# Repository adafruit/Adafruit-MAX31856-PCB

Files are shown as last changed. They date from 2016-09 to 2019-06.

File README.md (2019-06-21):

## Adafruit MAX31856 PCB

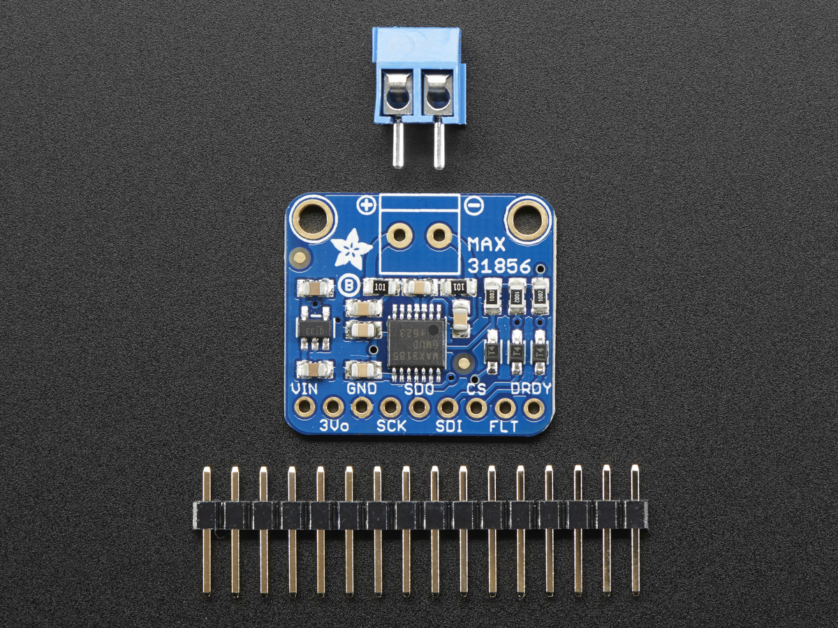
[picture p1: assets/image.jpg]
<a href="http://www.adafruit.com/products/3263"><br/>
Click here to purchase one from the Adafruit shop</a>

PCB files for the Adafruit MAX31856 Thermocouple Amplifier Breakout. Format is EagleCAD schematic and board layout
* https://www.adafruit.com/product/3263

### Description

Thermocouples are very sensitive, requiring a good amplifier with a cold-compensation reference, as well as calculations to handle any non-linearities. For a long time we've suggested our MAX31855K breakout, which works great but is only for K-type thermocouples. Now we're happy to offer a great new thermocouple amplifier/converter that can handle just about any type of thermocouple, and even has the ability to give you notification when the temperature goes out of range, or a fault occurs. Very fancy!

This converter communicates over 4-wire SPI and can interface with any K, J, N, R, S, T, E, or B type thermocouple.

This breakout does everything for you, and can be easily interfaced with any microcontroller, even one without an analog input. This breakout board has the chip itself, a 3.3V regulator and level shifting circuitry, all assembled and tested. Comes with a 2 pin terminal block (for connecting to the thermocouple) and pin header (to plug into any breadboard or perfboard). We even added inline resistors and a filter capacitor on-board for better stability, as recommended by Maxim. Goes great with our 1m K-type thermocouple or any other thermocouple, really!

### License

Adafruit invests time and resources providing this open source design, please support Adafruit and open-source hardware by purchasing products from [Adafruit](https://www.adafruit.com)!

Designed by Limor Fried/Ladyada for Adafruit Industries.

Creative Commons Attribution/Share-Alike, all text above must be included in any redistribution. See license.txt for additional details.

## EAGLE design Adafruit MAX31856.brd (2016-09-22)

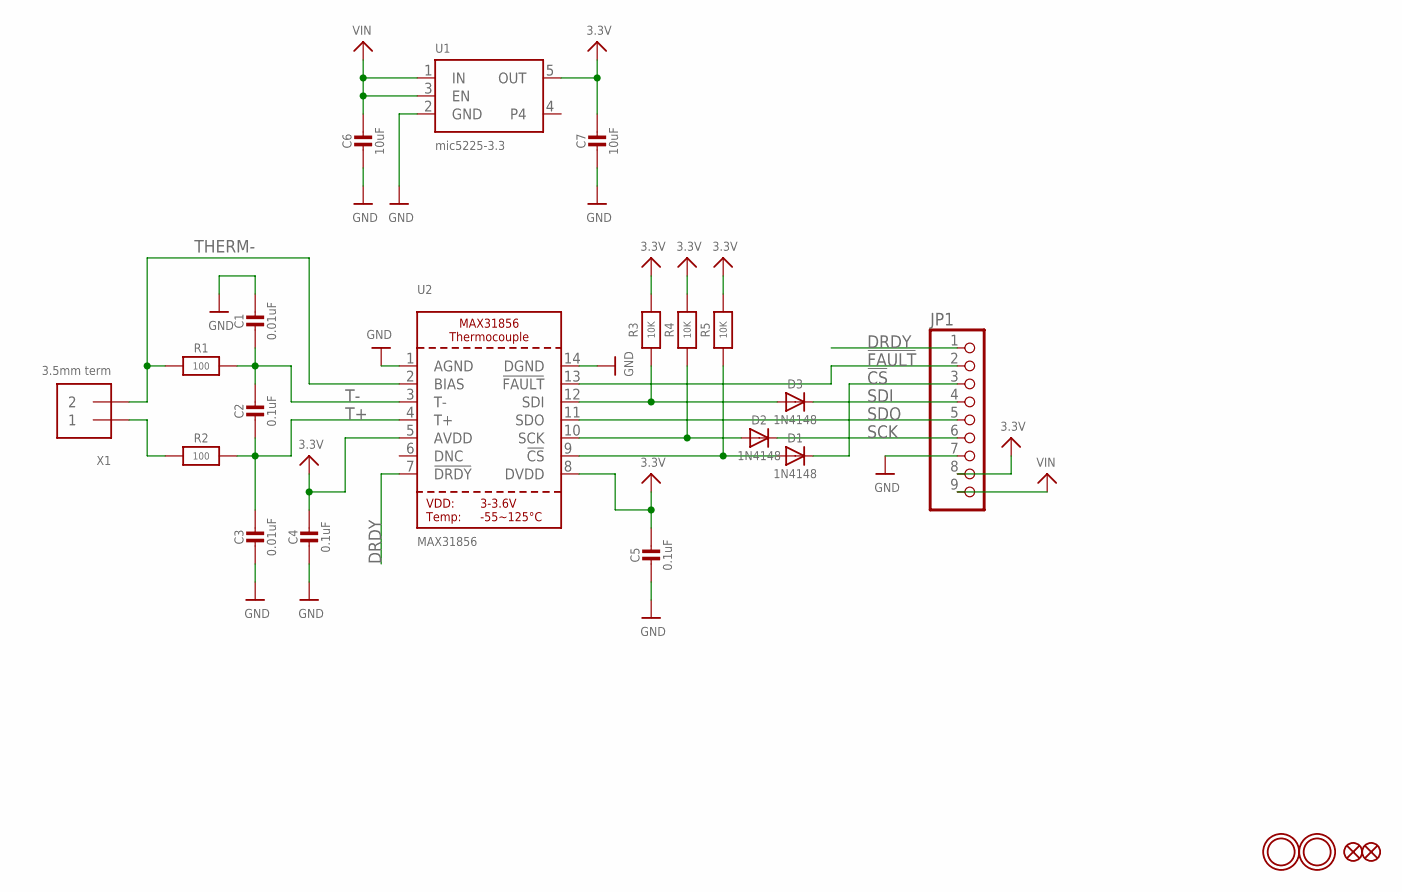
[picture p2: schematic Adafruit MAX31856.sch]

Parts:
C1: 0.01uF; 0805_10MGAP
C2, C4, C5: 0.1uF; 0805-NO
C3: 0.01uF; 0805-NO
C6, C7: 10uF; 0805-NO
D1, D2, D3: 1N4148; SOD-323
FID1, FID2: FIDUCIAL""; FIDUCIAL_1MM
JP1: HEADER-1X970MIL; 1X09_ROUND_70
R1, R2: 100; 0805-NO
R3, R4, R5: 10K; 0805-NO
U1: mic5225-3.3; SOT23-5
U2: MAX31856; TSSOP14
U$13, U$14: MOUNTINGHOLE2.5; MOUNTINGHOLE_2.5_PLATED
X1: 3.5mm term; TERMBLOCK_1X2-3.5MM

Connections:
3.3V: C4.1, C5.1, C7.1, JP1.8, R3.2, R4.2, R5.2, U1.5 (OUT), U2.5 (AVDD), U2.8 (DVDD)
!CS: D1.C, JP1.3
!CS_3V: D1.A, R5.1, U2.9 (!CS)
!FAULT: JP1.2, U2.13 (!FAULT)
DRDY: JP1.1, U2.7 (!DRDY)
GND: C1.1, C3.2, C4.2, C5.2, C6.2, C7.2, JP1.7, U1.2 (GND), U2.1 (AGND), U2.14 (DGND)
SCK: D2.C, JP1.6
SCK_3V: D2.A, R4.1, U2.10 (SCK)
SDI: D3.C, JP1.4
SDO: JP1.5, U2.11 (SDO)
SDO_3V: D3.A, R3.1, U2.12 (SDI)
T+: C2.2, C3.1, R2.2, U2.4 (T+)
T-: C1.2, C2.1, R1.2, U2.3 (T-)
THERM+: R2.1, X1.1
THERM-: R1.1, U2.2 (BIAS), X1.2
VIN: C6.1, JP1.9, U1.1 (IN), U1.3 (EN)

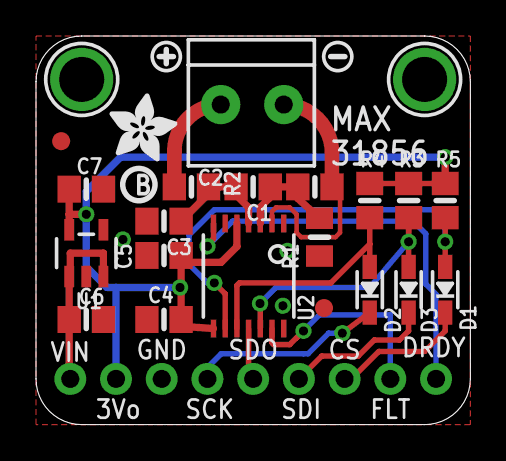
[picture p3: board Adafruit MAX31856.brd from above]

Board: 2 copper layers, 24.1 x 21.6 mm, 28 parts (1 on the bottom side), 16 nets.

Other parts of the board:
U$1: PCBFEAT-REV-040
U$23: SYMBOL_PLUS
U$24: SYMBOL_MINUS
U$25: ADAFRUIT_3.5MM
U$26: ADAFRUIT_TEXT_20MM

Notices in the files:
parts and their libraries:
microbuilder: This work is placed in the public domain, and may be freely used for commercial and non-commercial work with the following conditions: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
